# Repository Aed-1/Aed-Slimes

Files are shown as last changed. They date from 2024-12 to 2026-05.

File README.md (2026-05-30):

# Aed-Slimes
My design of PCB and case for NRF slime trackers 



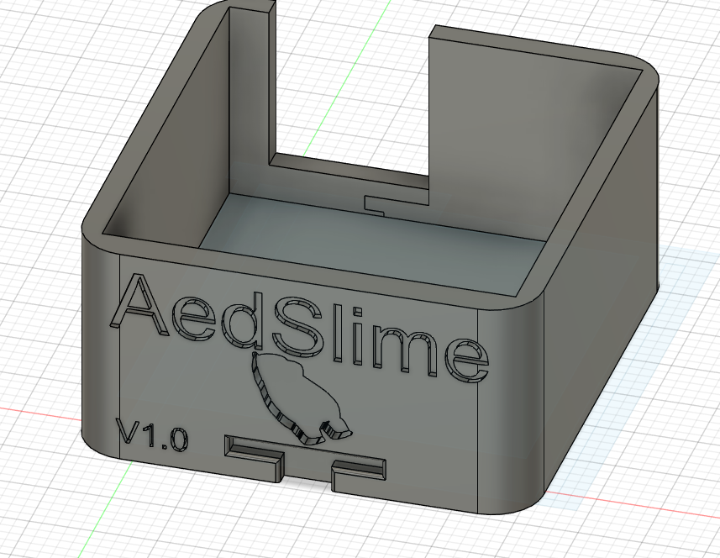
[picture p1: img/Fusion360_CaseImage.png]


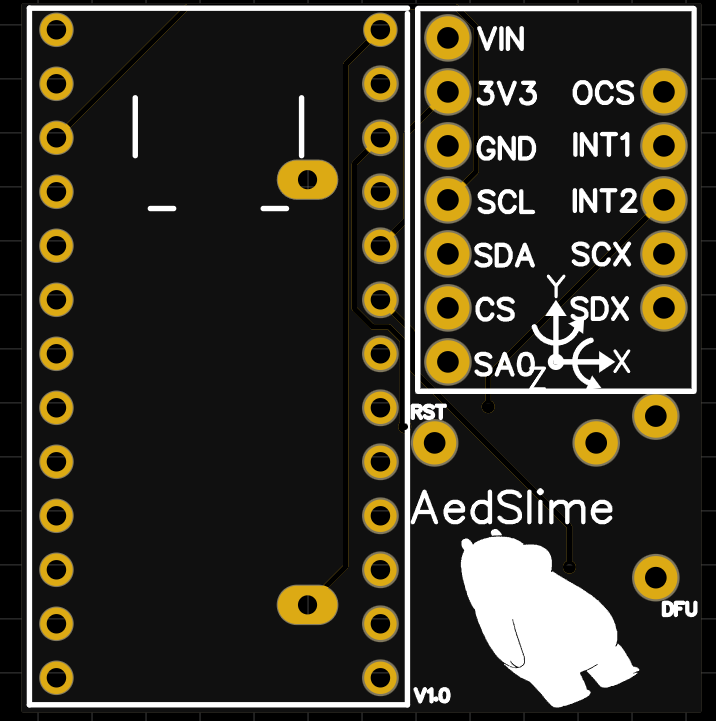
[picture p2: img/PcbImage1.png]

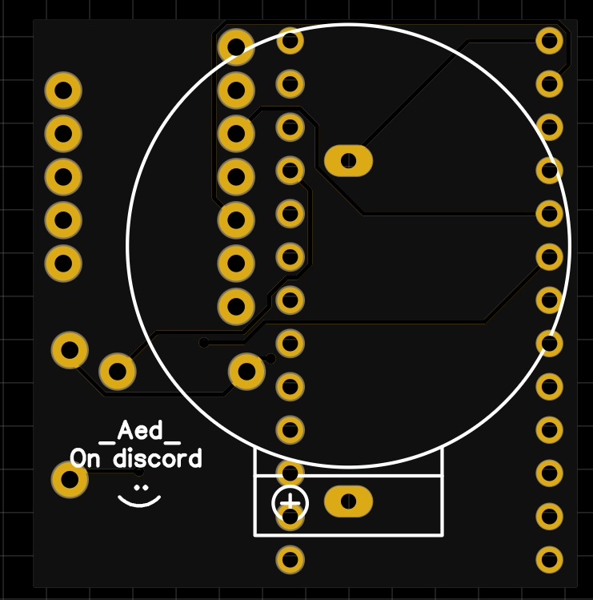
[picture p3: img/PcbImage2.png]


# Ordering PCB

download the Aed_Slime_Gerber.zip file from the PCB folder on this repo

go to https://jlcpcb.com and follow the steps shown below

step 1


step 2



step 3



step 4



step 5



step 6



step 7



step 8



# Parts List

- SuperMini NRF52840 (https://www.aliexpress.com/item/1005007738886550.html?spm=a2g0o.order_list.order_list_main.11.53071802maORE3)
  
- IMU of your choice (refer to https://docs.slimevr.dev/diy/imu-comparison.html)
  
- the PCB
  
- male 2.54mm header pins (https://www.aliexpress.com/item/1005005990753794.html?spm=a2g0o.order_list.order_list_main.84.53071802maORE3)
  
- LIR2450 coin battery (For V1.2 use battery with welded pins, i recommend the ones on amazon by EEMB. For V1.1 use any LIR2450 battery, just make sure its not LIR2450-H)

- For V1.1 only: case holder for battery (https://www.aliexpress.com/item/32809235496.html?spm=a2g0o.order_list.order_list_main.57.a29b1802v9RgP)
  
- 3d printed cases and strap hooks
  
- holyIOT Dongle (can be found on aliexpress, not linking seller due to them chaning all the time)
  
- push buttons (https://www.aliexpress.com/item/32882161197.html?spm=a2g0o.order_list.order_list_main.34.53071802maORE3) (you can get either color it doesnt matter)
  
- straps (https://shop.slimevr.dev/products/official-slimevr-straps-v2) (or any other 35mm wide strap) (buy according to the amount of trackers you have)
  
- basic soldering gear, kapton tape and flush cutters

# Building Trackers

for right now there is no image/video guide so you will have to make do with text for now, sorry D:

__IF YOU DO NOT FOLLOW THIS ORDER OF INSTRUCTIONS THE PARTS MIGHT NOT FIT!!!!__

__MAKE SURE EVERYTHING EXCEPT THE BATTERY IS SOLDERED ON THE SIDE WITH THE LOGO OTHERWISE THE PINS WILL BE BACKWARDS AND THE TRACKER WONT WORK__

First up, you need to decide between V1.1 and V1.2 of this tracker. the difference is that V1.2 has a soldered battery, whereas V1.1 uses a battery holder. This means that V1.1 allows you to replace the battery if you find your current one is bad, at the cost of it being roughly 5mm taller, which doesnt sound like much, but at sizes like these it is alot.

For the V1.2 guide, see below. For the V1.1 guide, please look below the V1.2 instructions to see the bold text saying "V1.1 GUIDE!"

__V1.2 GUIDE!__
1. Solder buttons onto the PCB, it is a very tight fit and dont be afraid to bend the pins a little bit, if they snap off you always have replacements as these buttons usually come in packs of 50/100
 
2. Solder pin headers onto the PCB

3. cut the pins on the underside of the pcb to make room for the battery

4. Stick kapton tape to bottom of PCB covering all pins apart from the 2 battery pins (this is not 100% necessary but is HIGHLY recomended as if you accidentally short the battery to the pins while in use or building it, you will fry your promicro board and risk a fire)
 
5. now solder the supermini and IMU onto the board making sure the USB-C port is on the side with the silkscreen of it (some components near the pins at the top of the supermini are very small so be careful not to accidentally bridge them)

6. solder battery on the PCB making sure the positive and negative terminals match accordingly
 
7. Finally, put the tracker into the case (might be a tight fit depending on which printer you used and its tolerences, just push on it and dont worry about the tracker snapping. you probably couldnt snap it if you tried.)

__V1.1 GUIDE!__
1. Solder buttons onto the PCB, it is a very tight fit and dont be afraid to bend the pins a little bit, if they snap off you always have replacements as these buttons usually come in packs of 50/100
 
2. Solder pin headers onto the PCB

3. you can cut the bottom of the pin headers for the battery holder, just make sure the battery holder will actually benifit from this though, most of them have pins that get wider at some point to leave an intentional gap in the pcb and holder

4. Solder the battery holder on
 
5. now solder the supermini and IMU onto the board making sure the USB-C port is on the side with the silkscreen of it (some components near the pins at the top of the supermini are very small so be careful not to accidentally bridge / knock them)

7. Finally, put the tracker into the case (might be a tight fit depending on which printer you used and its tolerences, just push on it and dont worry about the tracker snapping. you probably couldnt snap it if you tried.)

# prerequisite for firmware flashing

you will need to download the nRF Connect for desktop app as well as all the modules for it listed on this section of the docs:
https://docs.slimevr.dev/diy/smol-slime.html#software

# Updating Bootloader
___YOU WILL NEED TO DO THIS BEFORE UPLOADING FIRMWARE ON TRACKERS OTHERWISE YOU RISK BRICKING YOUR TRACKERS___

Download the bootloader with the below link and flash by putting tracker into DFU mode and dragging the .uf2 file into the drive that appears:
https://github.com/SlimeVR/Adafruit_nRF52_Bootloader/releases/download/0.9.2-SlimeVR.7/update-slimenrf_promicro_bootloader-0.9.2-SlimeVR.7_nosd.uf2

# Flashing Tracker Firmware

Follow this guide on uploading firmware to your tracker
https://docs.slimevr.dev/smol-slimes/firmware/smol-flashing-firmware.html#flashing-the-firmware-using-uf2

# Flashing Dongle Firmware

Now you can follow this guide below to upload the firmware for your dongle
https://docs.slimevr.dev/smol-slimes/firmware/smol-flashing-firmware.html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

# What next?

Now you will need to follow the slimevr docs listed below in order to pair your trackers to your reciever as well as calibrate them:
https://docs.slimevr.dev/smol-slimes/firmware/smol-pairing-and-calibration.html

# Extra informatiom
if pressing the buttons make the tracker move around in the case you can reprint the tracker in a filament that doesnt deform easily or hot glue it into place, either option works but hot glue wont look as good

CASE DIMENSIONS: 35.20x37.04x15mm

STRAP LOOP DESIGNED BY PIXEL (pixel_lily on discord)

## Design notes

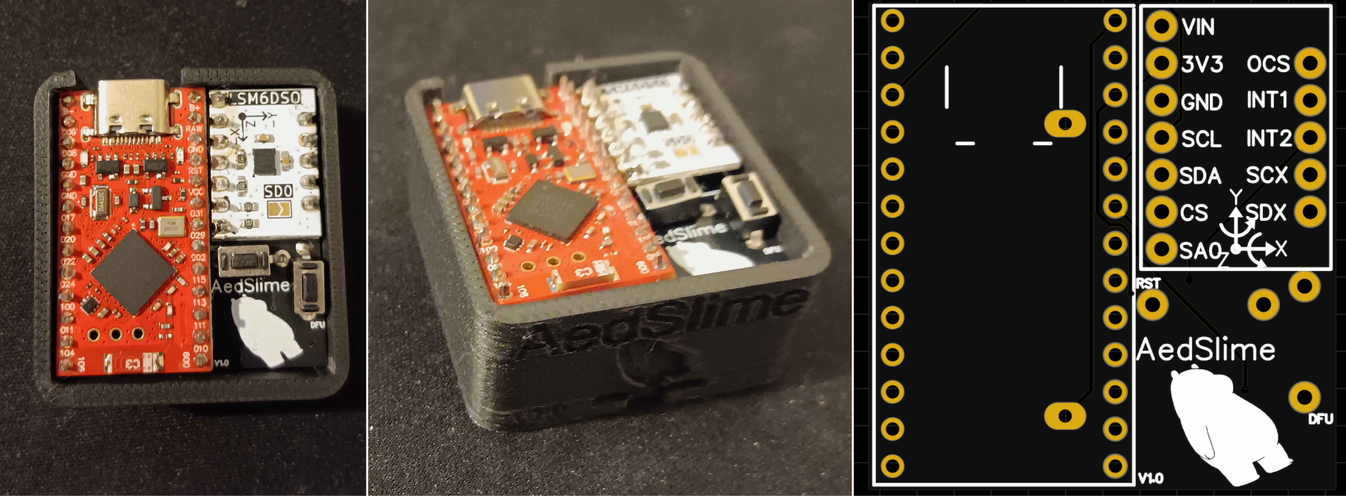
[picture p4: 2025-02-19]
img/Aed-Slime.png

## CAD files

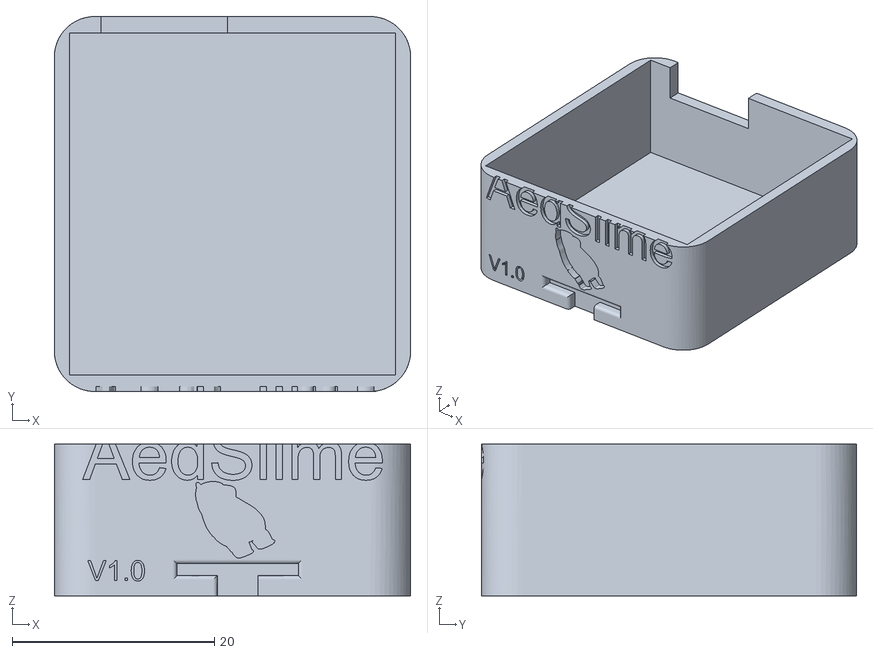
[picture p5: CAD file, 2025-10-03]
Printed files/Aed Slime Case V1.2.stl
35.2 x 37.0 x 15.0

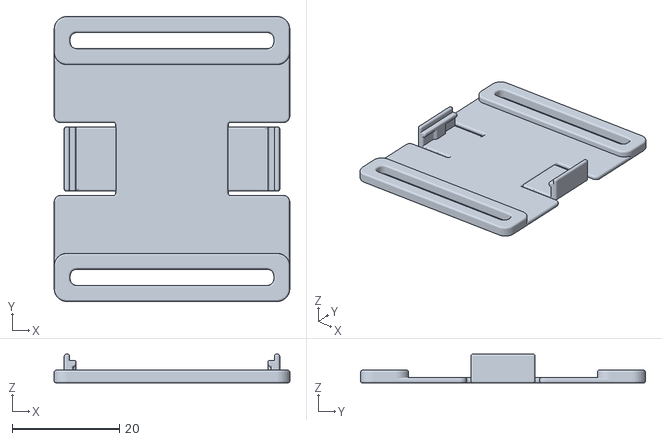
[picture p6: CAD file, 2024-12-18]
Printed files/pixel strap lock.stl
44.0 x 53.2 x 5.40

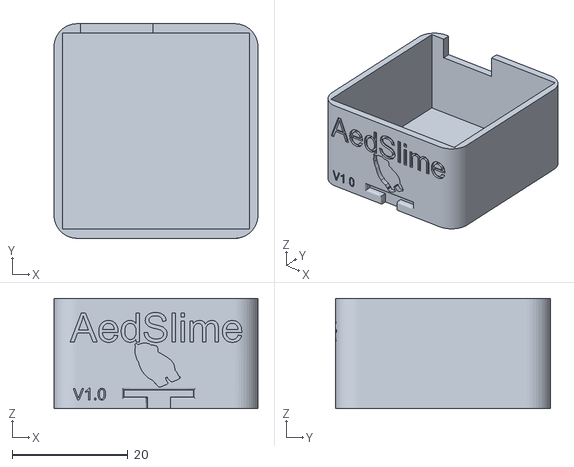
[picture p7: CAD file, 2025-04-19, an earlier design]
Printed files/Aed Slime Case V1.1.stl
35.2 x 37.0 x 19.0

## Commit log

2025-02-19 Rearranged images of case
2025-04-19 updated case design
    raised usb-c port cutout height as well as other minor fixes
    [Aed Slime Case.stl]
2025-06-10 added firmware for new SPI design
2025-06-10 added new tracker design
    updated for newer meia IMU breakout boards with the new ext_clk pin and SPI communication protocol
2026-05-30 Rename Aed Slime Case (5).stl to Aed Slime Case V1.2.stl
    [Aed Slime Case V1.2.stl]
2026-05-30 upload old case
    [Aed Slime Case V1.1.stl]
